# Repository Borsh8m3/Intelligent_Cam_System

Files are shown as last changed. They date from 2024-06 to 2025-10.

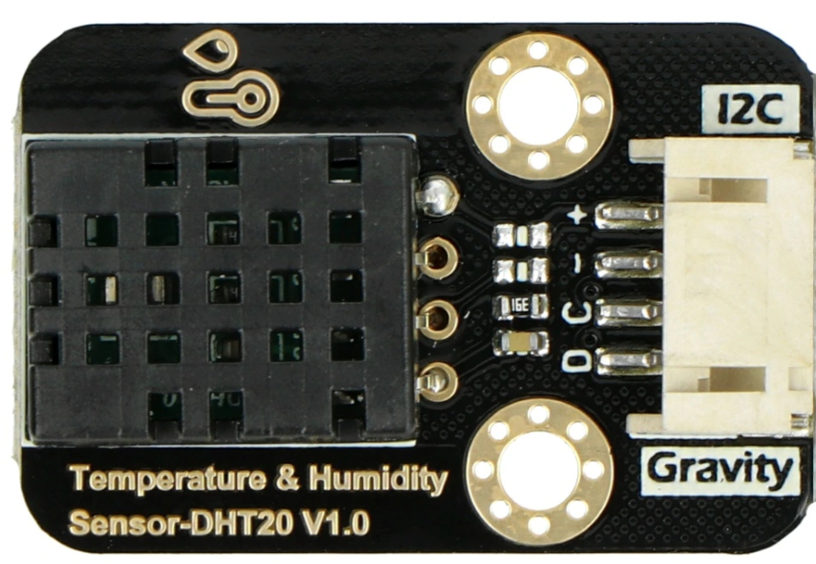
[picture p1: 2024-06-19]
documents/DHT20_onboard.png

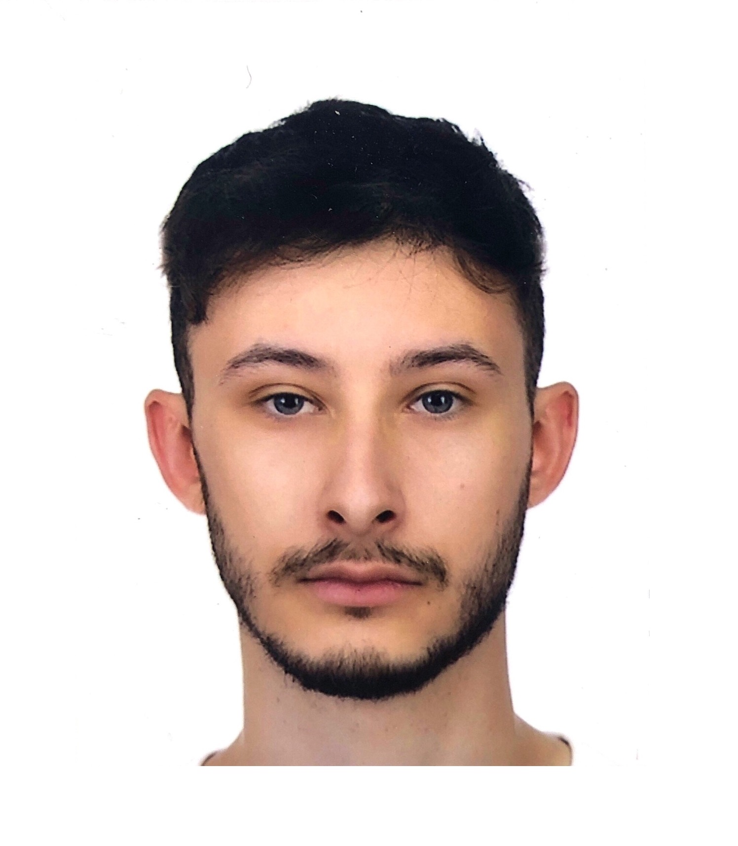
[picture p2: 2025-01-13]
code/Video detection/Machine/dawid_boratynski.jpg

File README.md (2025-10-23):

# Intelligent Cam System

## Introduction
The Intelligent Cam System is a modular surveillance camera designed to operate in demanding weather conditions. It combines a rugged hardware platform—featuring 360° rotation, environmental sensors, and inductive control—with a Python-based video analytics pipeline powered by OpenCV and the `face_recognition` library. The system continuously monitors its surroundings, localises people, and reacts automatically to changes in temperature, humidity, and precipitation.

## Key Features
- **360° camera movement** – dual servos provide full panoramic motion along the horizontal and vertical axes.
- **Weather protection** – a sealed enclosure with anti-condensation heating and a rain-activated wiper keeps the optics clear.
- **Environmental monitoring** – temperature, humidity, dew point, and rain intensity are measured in real time.
- **Real-time video analytics** – faces are detected, recognised, and logged for later review; unknown faces can be labelled semi-automatically.
- **Communication module** – live video can be streamed to an external processing unit or monitoring dashboard.

## System Architecture
### Hardware Layer
- Weather-resistant housing with the camera mounted on a two-axis gimbal.
- Two servomotors to control pan and tilt.
- A DHT11 sensor that monitors enclosure temperature and humidity.
- An inductively powered rain sensor connected through an ADC input.
- A heater or fan that activates when the calculated dew point is exceeded.
- A servo-driven wiper that runs when rainfall is detected.

### Software Layer
- **Enclosure control (MicroPython)** – `Insidecode.py` ingests sensor data and orchestrates the servos, heater, and status LED.
- **Video analysis (Python)** – the `Video detection` module uses OpenCV to load known face encodings, perform detection, and annotate the live preview.
- **Face database management** – new frames tagged as `Unknown` are stored for later review, enabling incremental updates to the gallery of known users.

## Repository Structure
```
Intelligent_Cam_System/
├── code/
│   ├── Insidecode.py          # MicroPython control logic for the enclosure
│   └── Video detection/
│       ├── main_video.py      # Main loop for face detection and logging
│       └── simple_facerec.py  # Helper class for encoding and recognising faces
├── documents/                 # Project documentation and schematics
├── Photographic documentation # Prototype photos
├── Case/                      # CAD / 3D-print files for the enclosure
└── ...
```

## Requirements
### MicroPython Module
- A MicroPython-compatible microcontroller board (e.g. Raspberry Pi Pico).
- Libraries: `machine`, `servo`, `dht`, `utime`, `math`.
- Sensors wired to the pins defined in `Insidecode.py`.

### Video Analysis Module
- Python 3.9 or newer.
- Packages: `opencv-python`, `face_recognition`, `numpy`.
- UVC-compatible camera.
- An `images/` directory containing reference face photos (`.jpg`/`.png`).

Set up a virtual environment and install the Python dependencies:
```bash
python -m venv .venv
source .venv/bin/activate  # Windows: .venv\Scripts\activate
pip install -r requirements.txt  # Create the file based on the list above
```

## Usage
### Enclosure Module (MicroPython)
1. Upload `Insidecode.py` to the microcontroller.
2. Verify the peripherals are connected:
   - Servo (GPIO 0)
   - DHT11 sensor (GPIO 26)
   - Push button (GPIO 12)
   - Heater or relay output (GPIO 13)
   - Status LED (GPIO 25)
   - Rain sensor connected to ADC 27
3. Run the script. The heater activates once the dew point threshold is crossed, and the wiper engages when rain intensity rises above roughly 25% of the sensor’s range.

### Video Analysis and Face Recognition
1. Populate the `images/` directory with files named `First_Last.jpg`. Files starting with `Unknown` will be treated as new profiles.
2. Update the `encoding_folder` path in `main_video.py` so it points to the image directory on your machine.
3. Launch the application:
   ```bash
   python "code/Video detection"/main_video.py
   ```
4. The program opens the live preview, highlights recognised faces, and saves frames for unknown persons. After stopping the script you can rename the captured images to add them to the known gallery.

## Future Improvements
- Integrate with external alarm or IoT systems.
- Synchronise the face database between the edge device and a central server.
- Extend object detection to non-human entities (vehicles, animals, etc.).
- Monitor power supply health and report hardware diagnostics.

## License
This project is provided for educational use. Ensure you have the right to process the images of individuals in your face recognition workflow.

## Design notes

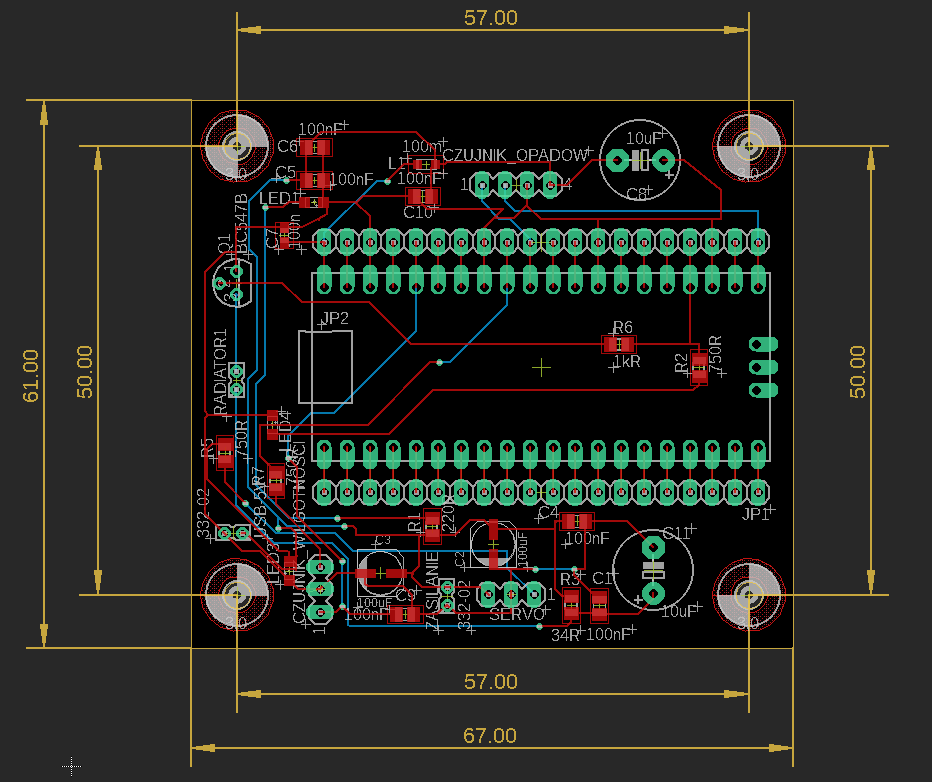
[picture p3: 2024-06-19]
Photographic documentation/Board diagram.png

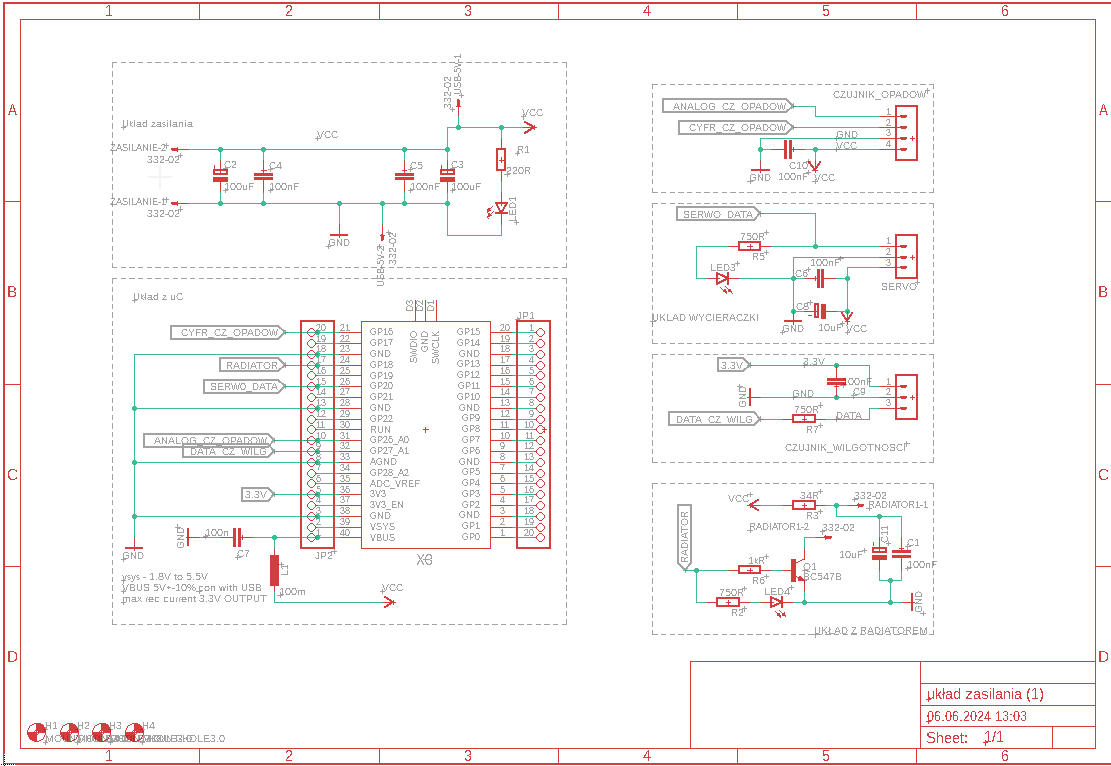
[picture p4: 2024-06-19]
Photographic documentation/Electric diagram.png

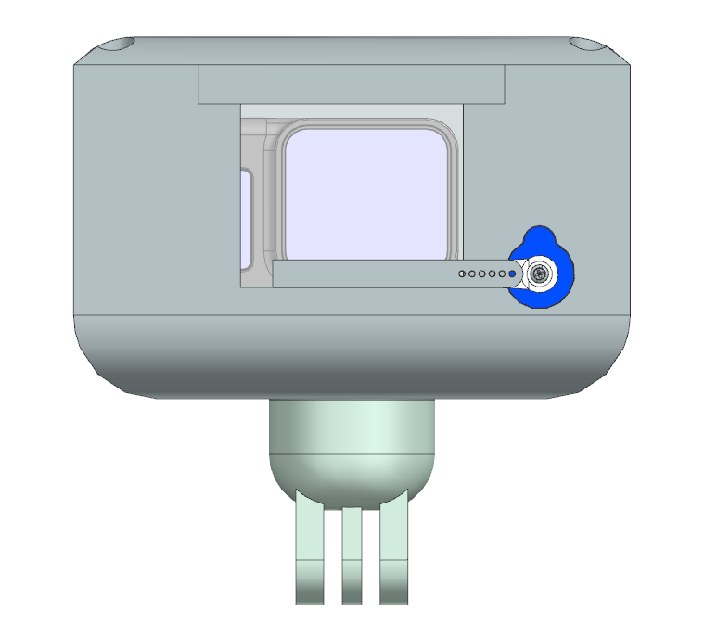
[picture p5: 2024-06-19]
Photographic documentation/case_front.png

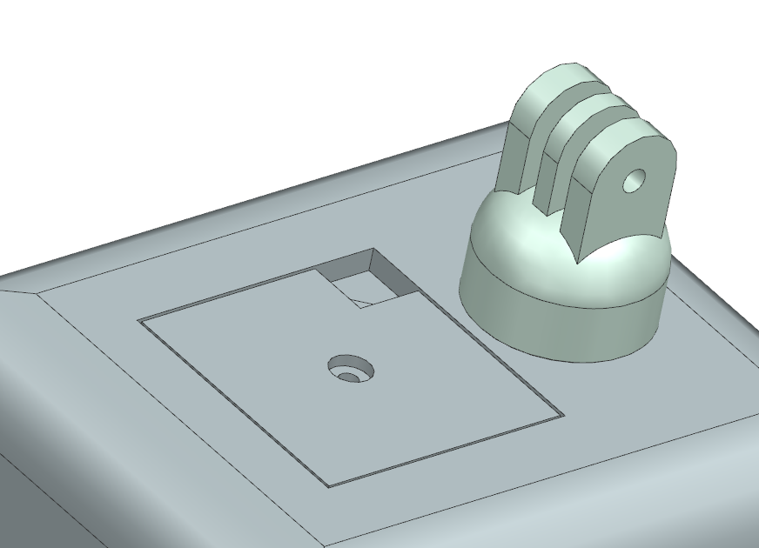
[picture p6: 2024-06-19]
Photographic documentation/case_lid.png

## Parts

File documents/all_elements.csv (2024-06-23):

Part | Value | Device | Package | Description | MF | MPN | OC_FARNELL | OC_NEWARK | POPULARITY | SPICEPREFIX
C1 | 100nF | C-EUC0805 | C0805 | CAPACITOR, European symbol |  |  |  |  | 88 | C
C2 | 100uF | CPOL-EUUD-5X5,8 | UD-5X5,8_NICHICON | POLARIZED CAPACITOR, European symbol |  |  |  |  | 0 | C
C3 | 100uF | CPOL-EUUD-5X5,8 | UD-5X5,8_NICHICON | POLARIZED CAPACITOR, European symbol |  |  |  |  | 0 | C
C4 | 100nF | C-EUC0805 | C0805 | CAPACITOR, European symbol |  |  |  |  | 88 | C
C5 | 100nF | C-EUC0805 | C0805 | CAPACITOR, European symbol |  |  |  |  | 88 | C
C6 | 100nF | C-EUC0805 | C0805 | CAPACITOR, European symbol |  |  |  |  | 88 | C
C7 | 100n | C-EUC0603 | C0603 | CAPACITOR, European symbol |  |  |  |  | 73 | C
C8 | 10uF | CPOL-EUE5-8.5 | E5-8,5 | POLARIZED CAPACITOR, European symbol |  |  |  |  | 0 | C
C9 | 100nF | C-EUC0805 | C0805 | CAPACITOR, European symbol |  |  |  |  | 88 | C
C10 | 100nF | C-EUC0805 | C0805 | CAPACITOR, European symbol |  |  |  |  | 88 | C
C11 | 10uF | CPOL-EUE5-8.5 | E5-8,5 | POLARIZED CAPACITOR, European symbol |  |  |  |  | 0 | C
CZUJNIK_OPADOW |  | MA04-1 | MA04-1 | PIN HEADER |  |  | unknown | unknown | 41
CZUJNIK_WILGOTNOSCI |  | MA03-1 | MA03-1 | PIN HEADER |  |  | unknown | unknown | 48
H1 | MOUNT-HOLE3.0 | MOUNT-HOLE3.0 | 3,0 | MOUNTING HOLE with drill center marker |  |  |  |  | 3
H2 | MOUNT-HOLE3.0 | MOUNT-HOLE3.0 | 3,0 | MOUNTING HOLE with drill center marker |  |  |  |  | 3
H3 | MOUNT-HOLE3.0 | MOUNT-HOLE3.0 | 3,0 | MOUNTING HOLE with drill center marker |  |  |  |  | 3
H4 | MOUNT-HOLE3.0 | MOUNT-HOLE3.0 | 3,0 | MOUNTING HOLE with drill center marker |  |  |  |  | 3
JP1 |  | PINHD-1X20 | 1X20 | PIN HEADER |  |  |  |  | 6
JP2 |  | PINHD-1X20 | 1X20 | PIN HEADER |  |  |  |  | 6
L1 | 100m | L-EUL2012C | L2012C | INDUCTOR, European symbol |  |  |  |  | 2 | L
LED1 |  | LEDSML0805 | SML0805 | LED |  |  |  |  | 17
LED3 |  | LEDSML0805 | SML0805 | LED |  |  |  |  | 17
LED4 |  | LEDSML0805 | SML0805 | LED |  |  |  |  | 17
Q1 | BC547B | BC547B | TO92 | NPN Transistor |  |  |  |  | 47
R1 | 220R | R-EU_R0805 | R0805 | RESISTOR, European symbol |  |  |  |  | 86 | R
R2 | 750R | R-EU_R0805 | R0805 | RESISTOR, European symbol |  |  |  |  | 86 | R
R3 | 34R | R-EU_R0805 | R0805 | RESISTOR, European symbol |  |  |  |  | 86 | R
R5 | 750R | R-EU_R0805 | R0805 | RESISTOR, European symbol |  |  |  |  | 86 | R
R6 | 1kR | R-EU_R0805 | R0805 | RESISTOR, European symbol |  |  |  |  | 86 | R
R7 | 750R | R-EU_R0805 | R0805 | RESISTOR, European symbol |  |  |  |  | 86 | R
RADIATOR1 | 332-02 | 332-02 | 332-02 | 2 Pin - 2mm Dual Row |  |  |  |  | 7
SERVO |  | MA03-1 | MA03-1 | PIN HEADER |  |  | unknown | unknown | 48
USB-5V | 332-02 | 332-02 | 332-02 | 2 Pin - 2mm Dual Row |  |  |  |  | 7
X3 |  | RPI_PICO_IG-TH | RPI_PICO_TH
ZASILANIE | 332-02 | 332-02 | 332-02 | 2 Pin - 2mm Dual Row |  |  |  |  | 7

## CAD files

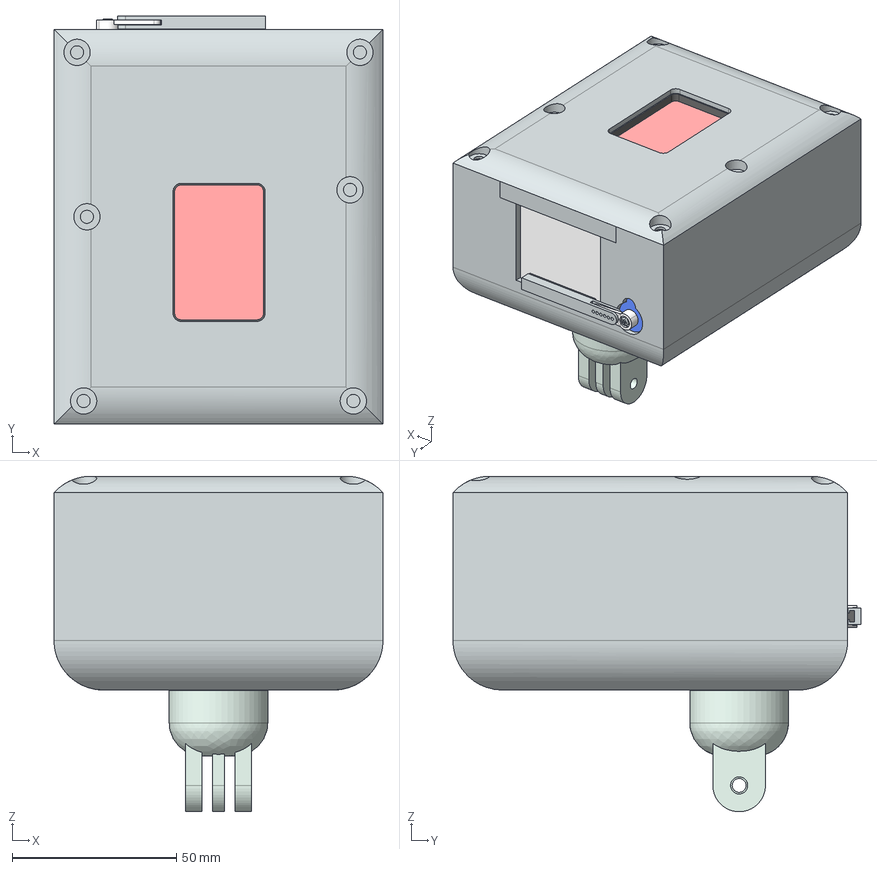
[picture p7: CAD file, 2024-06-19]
Case/case.stp
100.0 x 124.1 x 102.0 mm
radiator
uzwojenie x 2
pokrywka x 2
AAA hero5_stp
płytka
AAA SG90_sldprt
AAA nadproze
AAA pokrywka
AAA SMIGLO
AAA Uchwyt
AAA wycieraczka
AAA pióro
AAA USZCZELKA DUZA
czujnik_YL-83
AAA uszczelka mala
AAA szybka

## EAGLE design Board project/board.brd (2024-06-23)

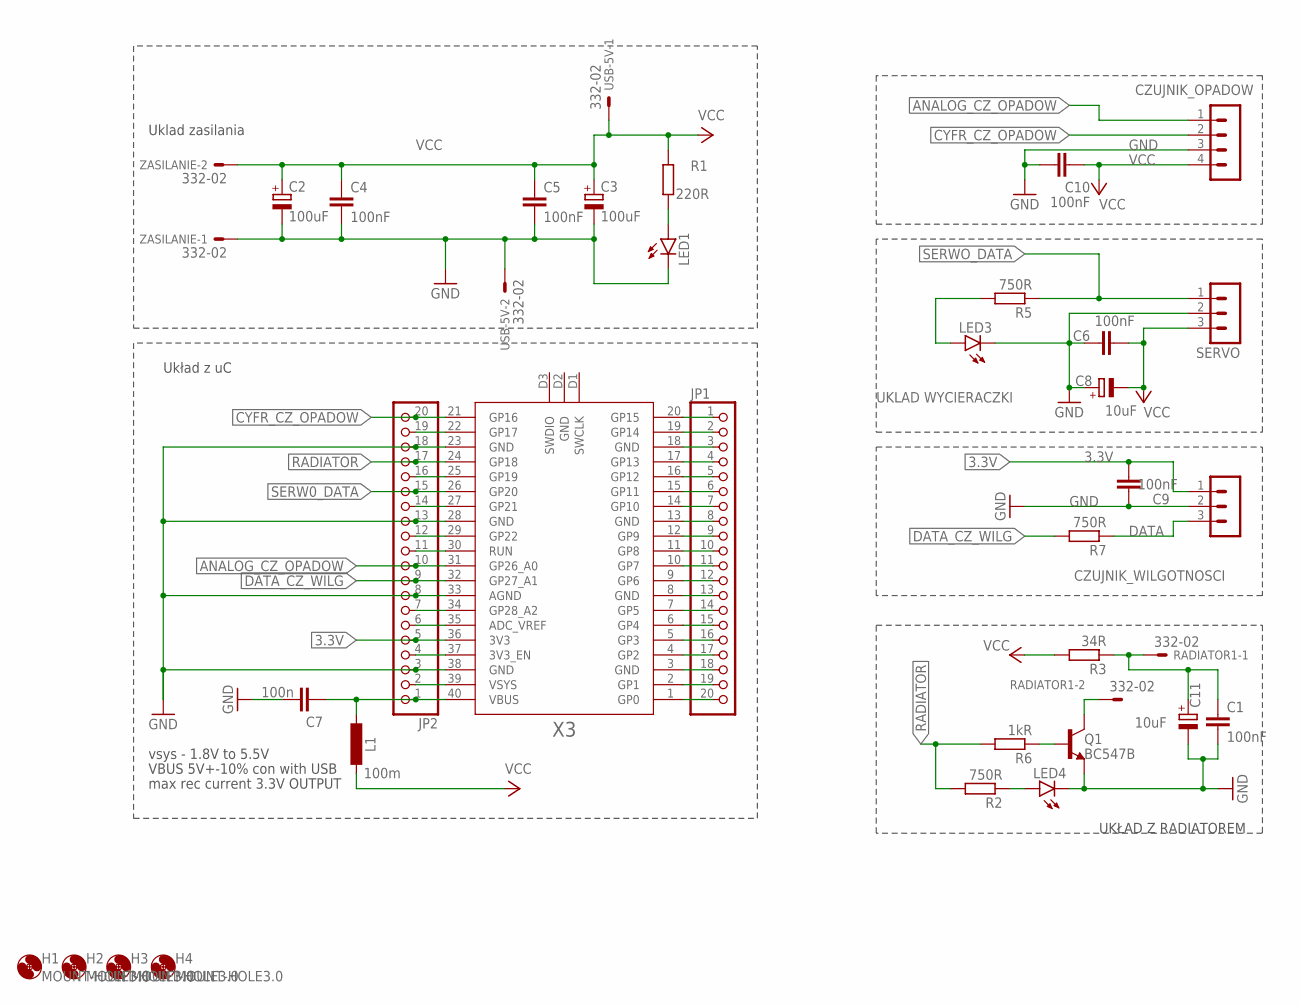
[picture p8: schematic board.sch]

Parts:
C1, C4, C5, C6, C9, C10: 100nF; C0805
C2, C3: 100uF; UD-5X5,8_NICHICON
C7: 100n; C0603
C8, C11: 10uF; E5-8,5
CZUJNIK_OPADOW: MA04-1
CZUJNIK_WILGOTNOSCI: MA03-1
H1, H2, H3, H4: MOUNT-HOLE3.0; 3,0
JP1, JP2: PINHD-1X20; 1X20
L1: 100m; L2012C
LED1, LED3, LED4: LEDSML0805; SML0805
Q1: BC547B; TO92
R1: 220R; R0805
R2, R5, R7: 750R; R0805
R3: 34R; R0805
R6: 1kR; R0805
RADIATOR1: 332-02
SERVO: MA03-1
USB-5V: 332-02
X3: RPI_PICO_IG-TH; RPI_PICO_TH
ZASILANIE: 332-02

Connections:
3.3V: C9.2, CZUJNIK_WILGOTNOSCI.1, JP2.5, X3.36 (3V3)
ANALOG_CZ_OPADOW: CZUJNIK_OPADOW.1, JP2.10, X3.31 (GP26_A0)
CYFR_CZ_OPADOW: CZUJNIK_OPADOW.2, JP2.20, X3.21 (GP16)
DATA: CZUJNIK_WILGOTNOSCI.3, R7.1
DATA_CZ_WILG: JP2.9, R7.2, X3.32 (GP27_A1)
GND: C1.2, C2.-, C3.-, C4.2, C5.2, C6.1, C7.2, C8.+, C9.1, C10.2, C11.-, CZUJNIK_OPADOW.3, CZUJNIK_WILGOTNOSCI.2, JP2.3, JP2.8, JP2.13, JP2.18, LED1.C, LED3.C, LED4.C, Q1.1 (E), SERVO.2, USB-5V.2, X3.23 (GND), X3.28 (GND), X3.33 (AGND), X3.38 (GND), ZASILANIE.1
unnamed: JP2.19, X3.22 (GP17)
unnamed: LED1.A, R1.2
unnamed: Q1.3 (C), RADIATOR1.2
unnamed: Q1.2 (B), R6.1
unnamed: C7.1, JP2.1, L1.2, X3.40 (VBUS)
unnamed: LED4.A, R2.1
unnamed: JP2.16, X3.25 (GP19)
unnamed: LED3.A, R5.2
unnamed: R5.1, SERVO.1
unnamed: JP1.1, X3.20 (GP15)
unnamed: JP2.14, X3.27 (GP21)
unnamed: JP2.12, X3.29 (GP22)
unnamed: JP2.11, X3.30 (RUN)
unnamed: JP2.7, X3.34 (GP28_A2)
unnamed: JP2.6, X3.35 (ADC_VREF)
unnamed: JP2.4, X3.37 (3V3_EN)
unnamed: JP1.20, X3.1 (GP0)
unnamed: JP1.19, X3.2 (GP1)
unnamed: JP1.18, X3.3 (GND)
unnamed: JP1.17, X3.4 (GP2)
unnamed: JP1.16, X3.5 (GP3)
unnamed: JP1.15, X3.6 (GP4)
unnamed: JP1.14, X3.7 (GP5)
unnamed: JP1.13, X3.8 (GND)
unnamed: JP1.12, X3.9 (GP6)
unnamed: JP1.11, X3.10 (GP7)
unnamed: JP1.10, X3.11 (GP8)
unnamed: JP1.9, X3.12 (GP9)
unnamed: JP1.8, X3.13 (GND)
unnamed: JP1.7, X3.14 (GP10)
unnamed: JP1.6, X3.15 (GP11)
unnamed: JP1.5, X3.16 (GP12)
unnamed: JP1.4, X3.17 (GP13)
unnamed: JP1.3, X3.18 (GND)
unnamed: JP1.2, X3.19 (GP14)
unnamed: JP2.2, X3.39 (VSYS)
RADIATOR: JP2.17, R2.2, R6.2, X3.24 (GP18)
SERW0_DATA: JP2.15, X3.26 (GP20)
VCC: C2.+, C3.+, C4.1, C5.1, C6.2, C8.-, C10.1, CZUJNIK_OPADOW.4, L1.1, R1.1, R3.2, SERVO.3, USB-5V.1, ZASILANIE.2
VCC1: C1.1, C11.+, R3.1, RADIATOR1.1

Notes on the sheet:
Uklad zasilania
Układ z uC
vsys - 1.8V to 5.5V
VBUS 5V+-10%
max rec current 3.3V OUTPUT
con with USB
UKŁAD Z RADIATOREM
UKLAD WYCIERACZKI

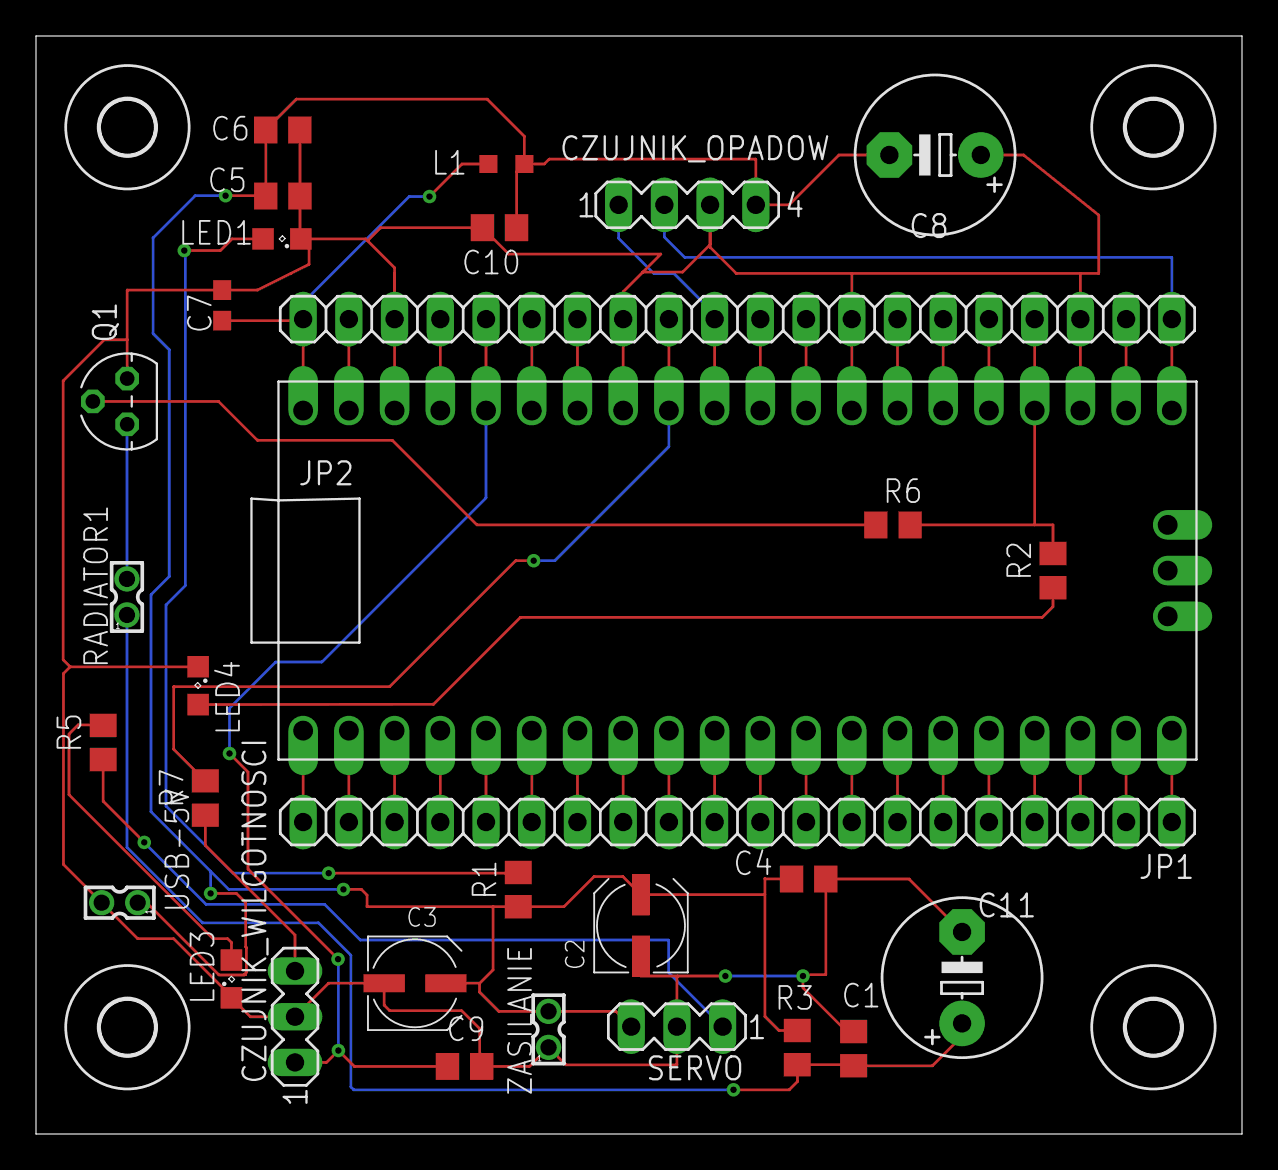
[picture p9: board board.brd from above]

Board: 2 copper layers, 67.0 x 61.0 mm, 35 parts (0 on the bottom side), 46 nets.

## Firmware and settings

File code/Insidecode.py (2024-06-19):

from time import sleep
from machine import Pin, ADC
from servo import Servo
import dht
import utime
import math

# Deklaracja połączeń fizycznych
servoPin = Servo(pin_id=0, min_us=544.0, max_us=2400.0, min_deg=0.0, max_deg=180.0, freq=50)
dht_sensor = dht.DHT11(Pin(26))
button = Pin(12, Pin.IN, Pin.PULL_UP)
radiator = Pin(13, Pin.OUT)
led = Pin(25, Pin.OUT)
adc = ADC(27)

# Deklaracja zmiennych globalnych
wspolczynnik_konwersji = 100 / 65535
delay_ms = 0.003
led.value(1)  # LED kontrolny

def ServoRun():
    for pos in range(0, 181, 1):
        servoPin.write(pos)
        sleep(delay_ms)
    for pos in range(180, -1, -1):
        servoPin.write(pos)
        sleep(delay_ms)

def Rain_Check():
    rain = 100 - (adc.read_u16() * wspolczynnik_konwersji)
    print('Opady:', rain)
    return rain

if char == block;
    then all 

def Dew_point(T, RH):
    a = 17.625  # Wsp. Magnusa zgodne z zaleceniami Alduchova i Eskridge'a
    b = 243.05
    A = math.log(RH / 100.0)
    dew_point = (b * (A + (a * T / (b + T)))) / (a - A)
    print("Dew point:", dew_point)
    return dew_point

def DHT_Check():
    try:
        dht_sensor.measure()
        temp = dht_sensor.temperature()
        hum = dht_sensor.humidity()
        print("temp:", temp, "hum:", hum)
        if Dew_point(temp, hum) > 20:
            return 1
        else:
            return 0
    except Exception as e:
        print("ERROR reading DHT11:", e)
        return 0

while True:
    if DHT_Check() == 1:
        radiator.value(1)
    else:
        radiator.value(0)    
    if Rain_Check() > 25:
        ServoRun()    
    utime.sleep(1)

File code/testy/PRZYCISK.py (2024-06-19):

import machine
import time

button = machine.Pin(12, machine.Pin.IN, machine.Pin.PULL_UP)
radiator = machine.Pin(16, machine.Pin.OUT)
led = machine.Pin(25, machine.Pin.OUT)
i = 1

led.value(1)

while True:
    first = button.value()
    time.sleep(0.01)
    second = button.value()
    if first and not second and i%2 == 1:
        print('ON:', i)
        radiator.value(1)
        i = i + 1
    elif first and not second and i%2 == 0:
        print('OFF:', i)
        radiator.value(0)
        i = i + 1

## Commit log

2024-06-19 Case update
2024-06-19 stp file
    [case.stp]
2024-06-23 board proj
    [all_elements.csv, board.brd, board.sch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]
